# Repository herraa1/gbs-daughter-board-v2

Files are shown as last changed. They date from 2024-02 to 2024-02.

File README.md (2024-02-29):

# GBS Control Daughter Board v2

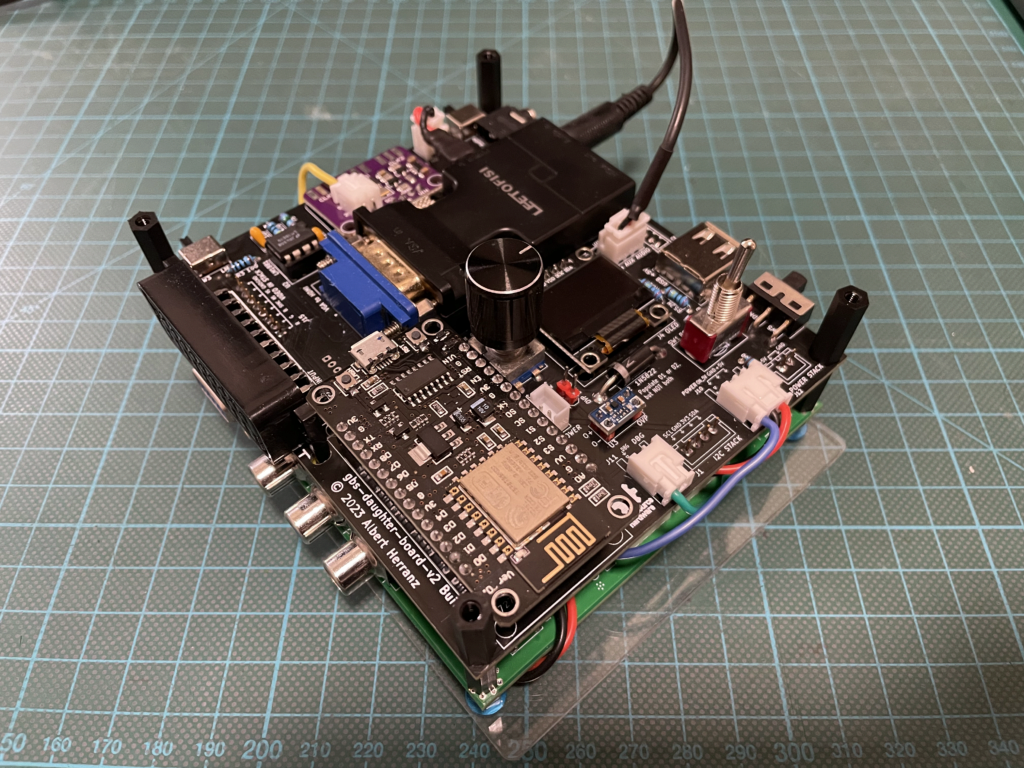
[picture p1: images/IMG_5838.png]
[](images/IMG_5838.png)

Enhance your [GBS8200](https://ramapcsx2.github.io/gbs-control/Wiki/Build-the-Hardware.html) upscaler board.

> [!WARNING]
> This is a work in progress project.
>
> An adapter based on PCB v2 Build1 has been successfully built
>
> No build instructions are yet provided
>

## Introduction

The GBS Daughter Board v2 is a companion board for the GBS8200 upscaler.
It facilitates the upgrade of an off-the-shelf GBS8200 board to a gbs-control firmware based solution, with the following main features:

* HAT-like design, simply stack the daughter board on top of the existing GBS8200
* add SCART RGB input
* add switchable HDMI output (via embedded VGA to HDMI dongle)
* add switchable sync stripper based on the LM1881
* add 3.5" jack sound output
* add switchable common or separate audio ground
* add auxiliar USB socket to optionally power external dongle
* add small OLED screen and rotary encoder for local control

## References

gbs-control
* https://github.com/ramapcsx2/gbs-control

GBS-C AIO
* https://github.com/amoore2600/GBS-C_AIO

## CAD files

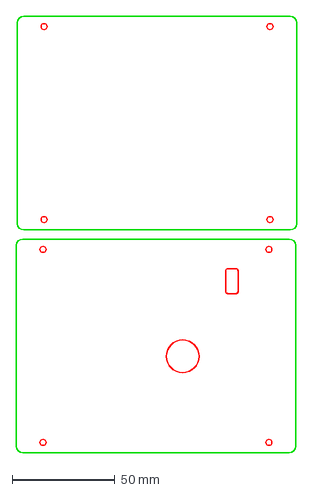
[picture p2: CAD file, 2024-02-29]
enclosure/gbs-daughter-board-v2-case-ready-to-lasercut.dxf
136.5 x 212.5 mm

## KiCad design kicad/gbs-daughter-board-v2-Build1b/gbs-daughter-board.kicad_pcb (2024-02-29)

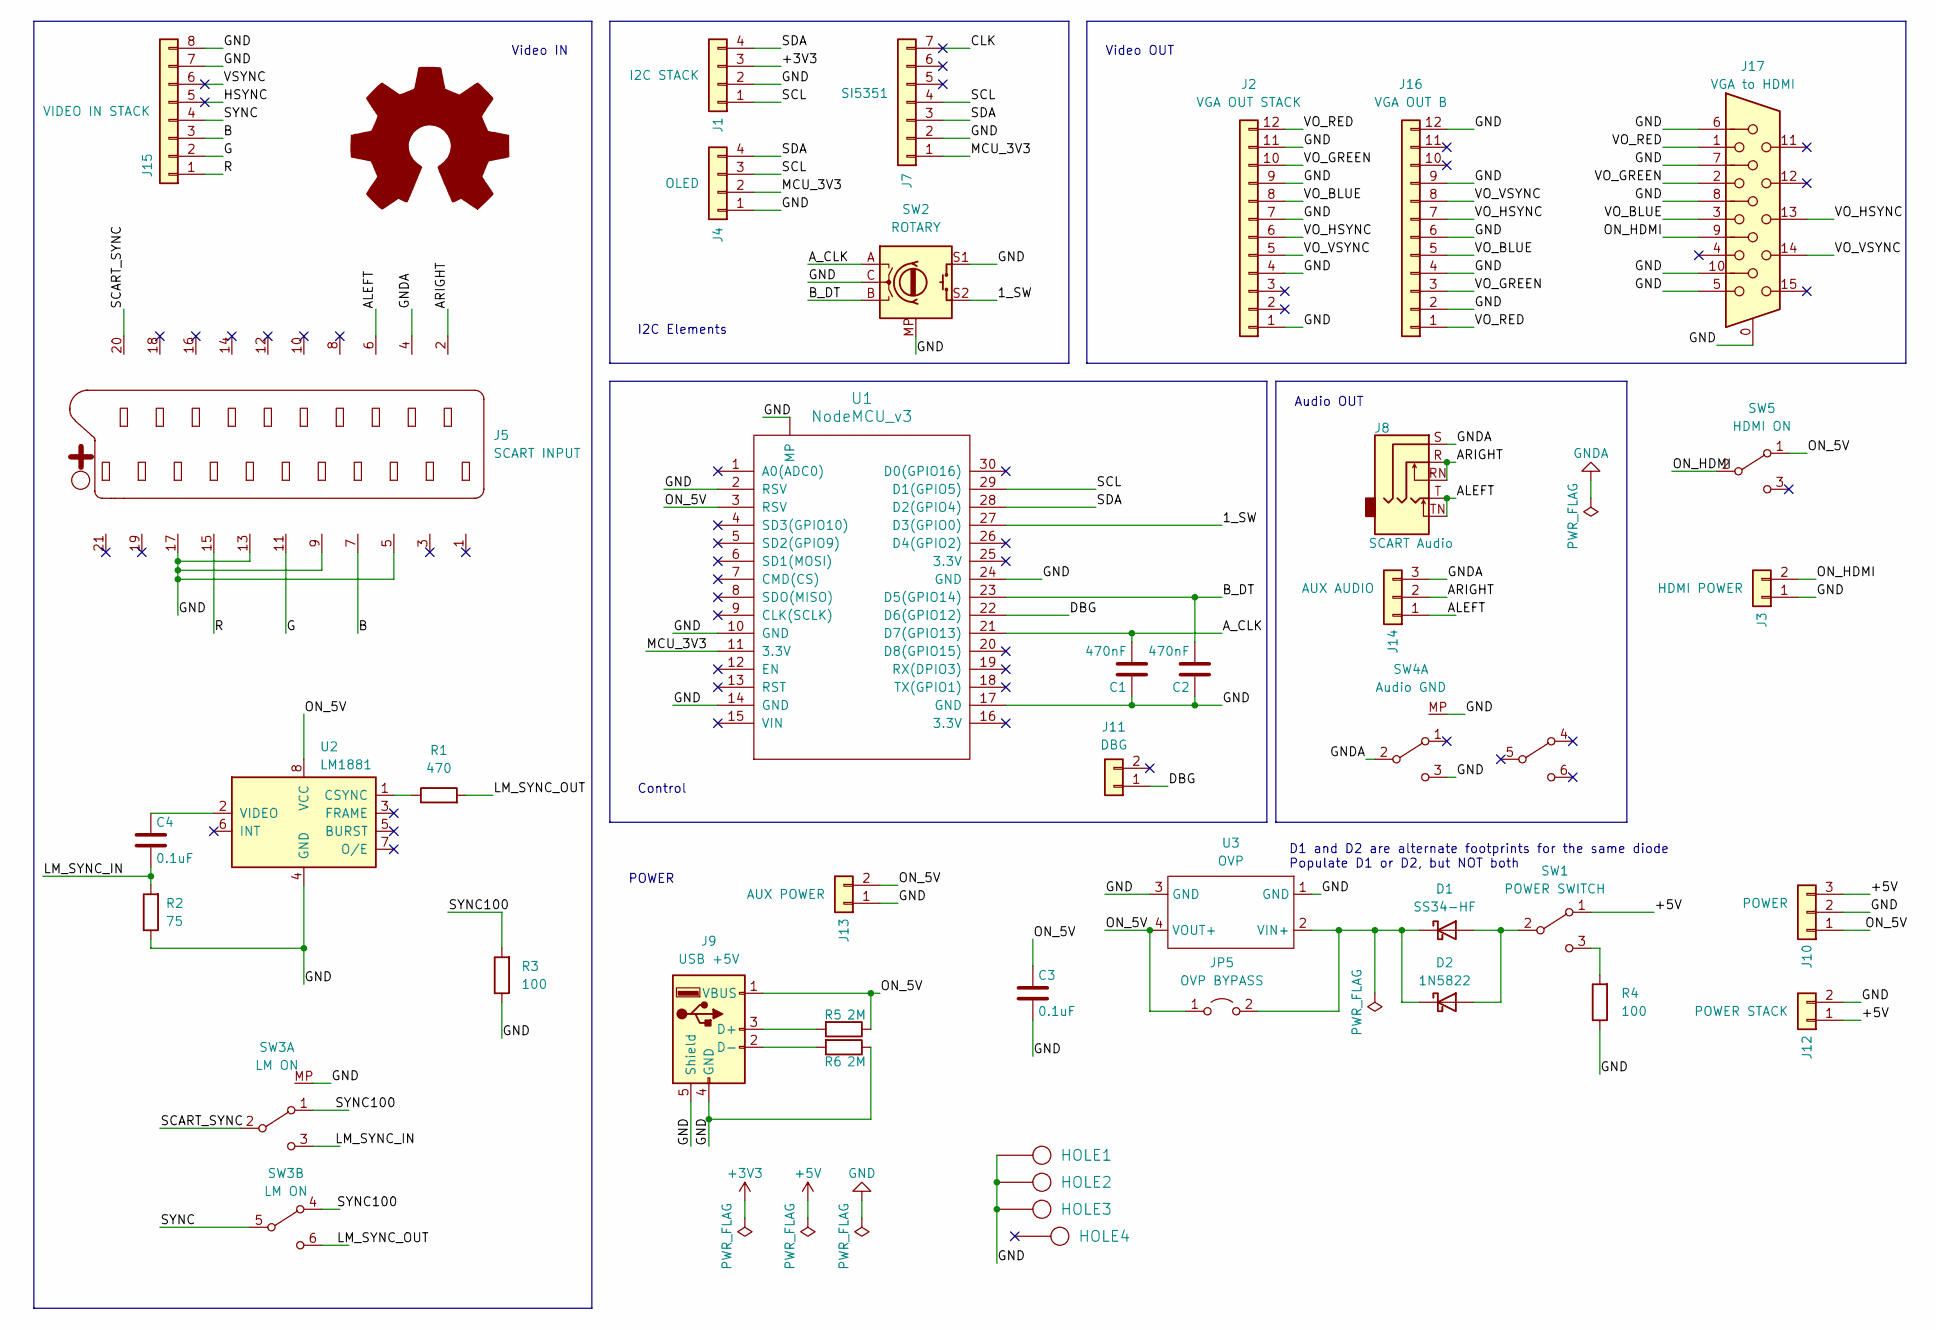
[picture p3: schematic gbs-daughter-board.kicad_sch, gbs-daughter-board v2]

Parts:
C1, C2: 470nF; Cap_Cer_508
C3, C4: 0.1uF; Cap_Cer_508
D1: SS34-HF; D_SMA_Handsoldering
D2: 1N5822; DIODE-DO-27-DO-201AD
HOLE1, HOLE2, HOLE3, HOLE4: HOLE; Hole_3mm
J1: I2C STACK; JST_XH_B4B-XH-A_1x04_P2.50mm_Vertical
J2: VGA OUT STACK; JST_PH_B12B-PH-K_1x12_P2.00mm_Vertical
J3: HDMI POWER; JST_XH_B2B-XH-A_1x02_P2.50mm_Vertical
J4: OLED; Display_128x64_096_I2C
J5: SCART INPUT; SCART
J7: SI5351; si5351a_Module
J8: SCART Audio; Jack_3.5mm_CUI_SJ1-3525N_Horizontal
J9: USB +5V; USB_A_CONNFLY_DS1095-WNR0
J10: POWER; JST_XH_S3B-XH-A_1x03_P2.50mm_Horizontal
J11: DBG; JST_XH_S2B-XH-A_1x02_P2.50mm_Horizontal
J12: POWER STACK; JST_XH_B2B-XH-A_1x02_P2.50mm_Vertical
J13: AUX POWER; JST_XH_B2B-XH-A_1x02_P2.50mm_Vertical
J14: AUX AUDIO; JST_XH_B3B-XH-A_1x03_P2.50mm_Vertical
J15: VIDEO IN STACK; Conn_1x08_P2.50mm
J16: VGA OUT B; JST_PH_S12B-PH-K_1x12_P2.00mm_Horizontal
J17: VGA to HDMI; DSUB-15-HD_Female_Horizontal_P2.29x1.98mm_EdgePinOffset3.03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
JP5: OVP BYPASS; Conn_Pin_Header_2x1_2.54mm_NoKey
R1: 470; Res_762
R2: 75; Res_762
R3, R4: 100; Res_762
R5, R6: 2M; Res_762
SW1: POWER SWITCH; SW_Toggle_Blue_wSlots
SW2: ROTARY; RotaryEncoder_Alps_EC11E-Switch_Vertical_H20mm_CircularMoun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
SW3: LM ON; SW_SK-22D07VG4-2P2T-4mm
SW4: Audio GND; SW_SK-22D07VG4-2P2T-4mm
SW5: HDMI ON; SW_SS-12D11
SYM1: Logo_Open_Hardware_Large; OSHW-Logo_7.5x8mm_SilkScreen
U1: NodeMCU_v3; NodeMCU-LoLinV3-LargePads
U2: LM1881; DIP-8_W7.62mm_Socket
U3: OVP; OVP_Module_5.5V_2.5A_30V

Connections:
+3V3: J1.3
+5V: J10.3, J12.1, SW1.1 (A)
/1_SW: SW2.S2, U1.27 (D3(GPIO0))
/ALEFT: J5.6, J8.T, J8.TN, J14.1
/ARIGHT: J5.2, J8.R, J8.RN, J14.2
/A_CLK: C1.2, SW2.A, U1.21 (D7(GPIO13))
/B: J5.7, J15.3
/B_DT: C2.2, SW2.B, U1.23 (D5(GPIO14))
/CLK: J7.7
/DBG: J11.1, U1.22 (D6(GPIO12))
/G: J5.11, J15.2
/HSYNC: J15.5
/LM_SYNC_IN: C4.2, R2.2, SW3.3 (C)
/LM_SYNC_OUT: R1.2, SW3.6 (C)
/MCU_3V3: J4.2, J7.1, U1.11 (3.3V)
/ON_5V: C3.1, J9.1 (VBUS), J10.1, J13.2, JP5.1 (A), R5.1, SW5.1 (A), U1.3 (RSV), U2.8 (VCC), U3.4 (VOUT+)
/ON_HDMI: J3.2, J17.9, SW5.2 (B)
/R: J5.15, J15.1
/SCART_SYNC: J5.20, SW3.2 (B)
/SCL: J1.1, J4.3, J7.4, U1.29 (D1(GPIO5))
/SDA: J1.4, J4.4, J7.3, U1.28 (D2(GPIO4))
/SYNC: J15.4, SW3.5 (B)
/SYNC100: R3.2, SW3.1 (A), SW3.4 (A)
/VO_BLUE: J2.8, J16.5, J17.3
/VO_GREEN: J2.10, J16.3, J17.2
/VO_HSYNC: J2.6, J16.7, J17.13
/VO_RED: J2.12, J16.1, J17.1
/VO_VSYNC: J2.5, J16.8, J17.14
/VSYNC: J15.6
GND: C1.1, C2.1, C3.2, HOLE1.1, HOLE2.1, HOLE3.1, J1.2, J2.1, J2.4, J2.7, J2.9, J2.11, J3.1, J4.1, J5.5, J5.9, J5.13, J5.17, J7.2, J9.4 (GND), J9.5 (Shield), J10.2, J12.2, J13.1, J15.7, J15.8, J16.2, J16.4, J16.6, J16.9, J16.12, J17.0, J17.5, J17.6, J17.7, J17.8, J17.10, R2.1, R3.1, R4.1, R6.1, SW2.C, SW2.MP, SW2.S1, SW3.MP, SW4.3 (C), SW4.MP, U1. (MP), U1.2 (RSV), U1.10 (GND), U1.14 (GND), U1.17 (GND), U1.24 (GND), U2.4 (GND), U3.1 (GND), U3.3 (GND)
GNDA: J5.4, J8.S, J14.3, SW4.2 (B)
unnamed: D1.2 (A), D2.2 (A), SW1.2 (B)
unnamed: D1.1 (K), D2.1 (K), JP5.2 (B), U3.2 (VIN+)
unnamed: J9.3 (D+), R5.2
unnamed: J9.2 (D-), R6.2
unnamed: R4.2, SW1.3 (C)
unnamed: R1.1, U2.1 (CSYNC)
unnamed: C4.1, U2.2 (VIDEO)

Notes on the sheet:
POWER
Control
I2C Elements
Video IN
Audio OUT
Video OUT
D1 and D2 are alternate footprints for the same diode Populate D1 or D2, but NOT both

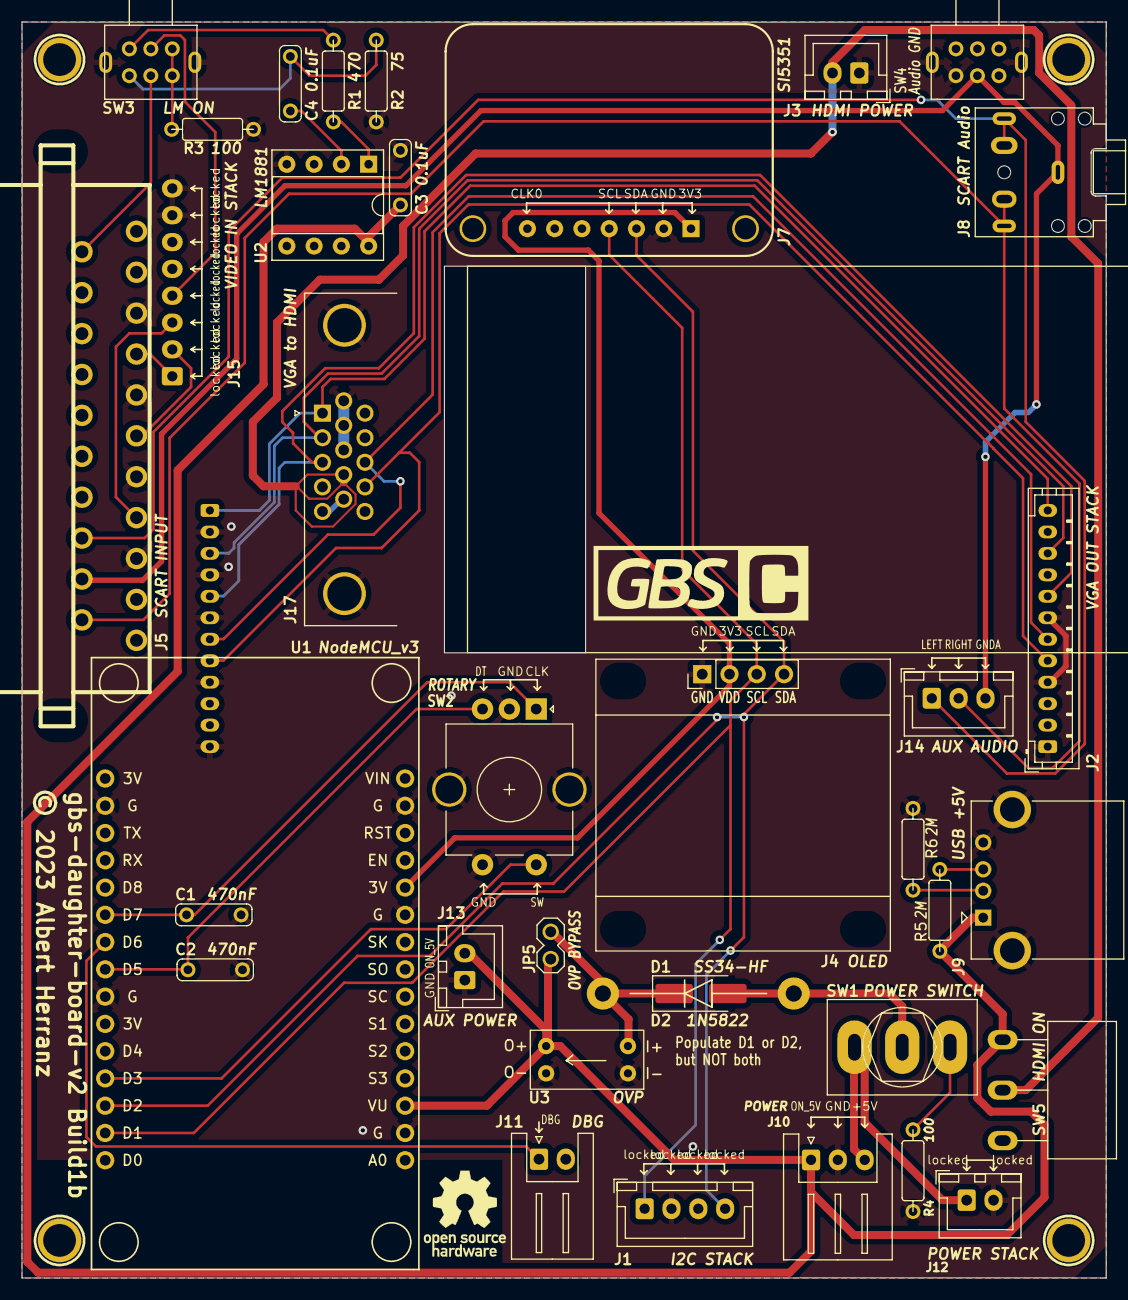
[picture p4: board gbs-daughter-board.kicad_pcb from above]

Board: 2 copper layers, 101.0 x 117.0 mm, 42 parts (1 on the bottom side), 34 nets.

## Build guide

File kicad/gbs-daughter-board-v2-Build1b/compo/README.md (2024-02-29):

kicad-ESP8266 - a library for KiCAD
=====================================
This project has both schematic symbols, footprints, and 3d models for
ESP8266 based modules. It is a work-in-progress. Additions and
corrections are welcome. Enter a pull request or file an issue on
GitHub.

The present modules are:

  * ESP-01  - Note that there are two versions of this module available on
              open market. The schematic symbol is for the `v090` version
              which is probably the same as the `v080`. There is an older
              version that does not include any GPIO signals. The footprint
              is the same for all of the ESP-01 modules.

  * ESP-12  - This is includes an alias part, ESP-07v2, that is suitable
              for the 16 pin variant of the ESP-07. Note that there is a 14
              pin version of the ESP-07 that has different signals and
              pinout. The footprint for the ESP-12 (and ESP-07v2)
              elongated through-hole pads to match those modules.

  * ESP-201 - This is a 26 pin module with pins on 0.1 inch spacing. I
              could not find any official measurements for the pin
              locations so the footprint was created from empirical
              measurements on the unit I have.

  * ESP-12E - This is for the 22 pin variant of the ESP-12. ~~Though all the 
              esp-12 signals are in the same place on ESP-12E, pin numbers
              have changed.~~ As of 2016/12/06 the pin numbers on the
              ESP-12E have been changed to be compatible with the
              ESP-12. If you need the old pin numbers they are still
              available on the `oldNumbers` branch.

  * ESP-07v2 - ESP-07 that is pin compatible with the ESP-12.

  * ESP-13-WROOM-02

  * There is a footprint for the ESP-06, but no supporting
      schematic symbol.

There are 3d models for the ESP-07v2, ESP-13, ESP-12 and ESP-12E.

WARNINGS
---------
  1. The symbols, footprints, and 3d models have not been tested. They are
     based on published images and measurements on individual samples.

  2. The `.dcm` file contains HTML links to information on sites I used
     when creating this library, however I do not have any control over
     the sites themselves. Follow the links with caution.

  3. This library distributed in the hope that it will be useful,
     but __WITHOUT ANY WARRANTY; without even the implied warranty of__
     __MERCHANTABILITY or FITNESS FOR A PARTICULAR PURPOSE__.

Use
---
 1. Clone this archive to a convenient location on your computer. These are
    the commands I use on Linux to create a copy in
    `~/kicad/libraries/kicad-ESP8266`:

        mkdir -p ~/kicad/libraries/
        cd ~/kicad/libraries/
        git clone https://github.com/jdunmire/kicad-ESP8266

 2. Add `ESP8266.lib` to the Component Libraries:

        eeschema:Preferences->Component Libraries->Add

 3. Add `ESP8266.pretty` to the Footprint Libraries:

        pcbnew:Preferences->Footprint Libraries Wizard

 4. To make the 3d models usable, add the location from step #1 to list
    of configured paths as `ESPLIB`. Use a full path. Continuing with
    the example step #1:

        kicad:Preferences->Configure Paths->Add

            Name: ESPLIB
            Path: /home/<your_login_name>/kicad/libraries/kicad-ESP8266

3D Models
---------
The 3D models were built using [OpenSCAD](http://www.openscad.org/) and
then colored in [Wings3D](http://www.wings3d.com/) to produce the VRML
(`.wrl`) format for KiCAD. Wings3D requires a binary STEP format, but
OpenSCAD writes an ASCII version.
[meshconv](http://www.patrickmin.com/meshconv/) will convert the
ASCII format to a binary format.

Here is the workflow I used:

 1. Use OpenScad to build the model. Export the model as STL.
    * Build using F6
    * File->Export...->Export as STL...

 2. Use `meshconv` to translate the file to binary.

        $ meshconv -c stl <STL-FILE-FROM-OpenSCAD> -o <FILENAME>

 3. Now open Wings3d and import the the `FILENAME.stl` as a
 _StereoLithography Binary File (*.stl)_.

 4. Assign colors.

 5. Export as _VRML 2.0 File (*.wrl)_

 6. The 3D model probably needs to be scaled to match the footprint. Use
    the `kicad:Footprint Editor:Edit->Edit Properties->3D Settings`
    dialog. For the ESP-12, the `Shape Scale` X, Y, and Z values are
    0.393700.

This repository includes all the intermediate files:

  * `.scad` - OpenSCAD model
  * `.stl` - OpenSCAD STL
  * `_4wings.stl` - STL file converted by `meshconv`
  * `.wings` - Wings3D model
  * `.wrl` - VRML model for KiCAD

License
-------
Copyright 2015,2016 J.Dunmire

Contact: jedunmire PLUS kicad-ESP8266 AT gmail DOT com

This file is part of kicad-ESP8266. 

kicad-ESP8266 is licensed under the Creative Commons Attribution-ShareAlike
4.0 International License. To view a copy of this license visit
http://creativecommons.org/licenses/by-sa/4.0/.

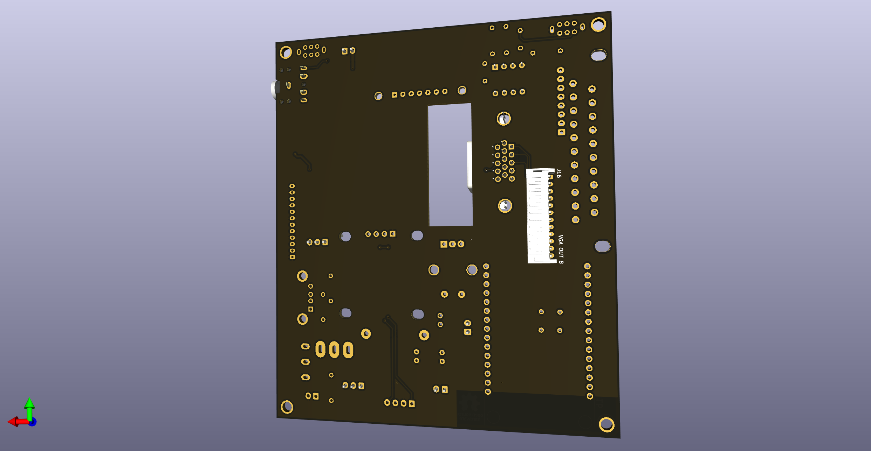
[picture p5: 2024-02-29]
images/gbs-daughter-board-v2-build1b-back.png

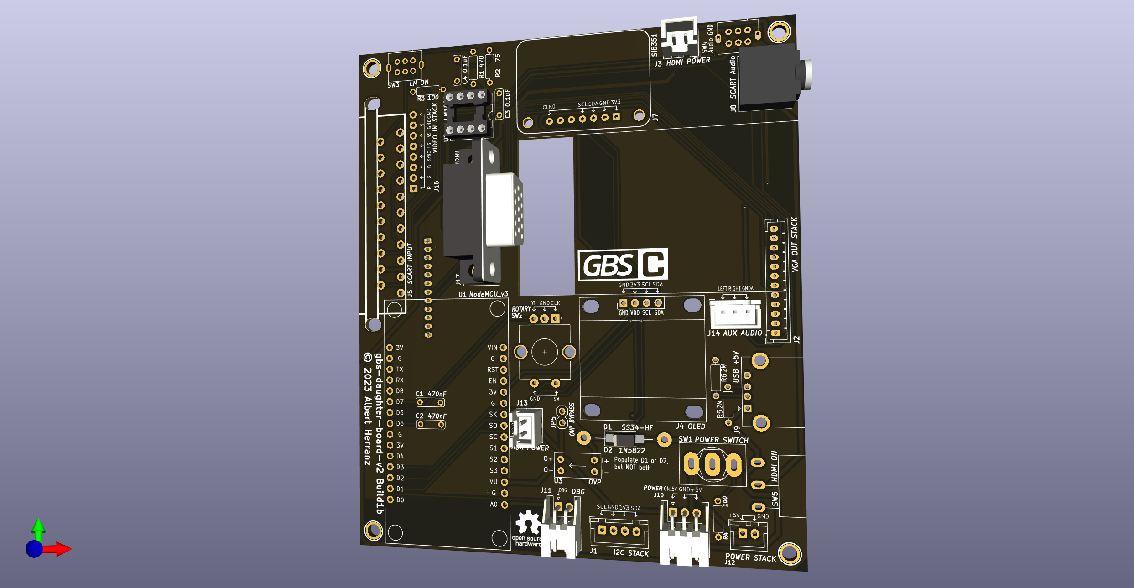
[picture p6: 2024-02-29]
images/gbs-daughter-board-v2-build1b-front.png

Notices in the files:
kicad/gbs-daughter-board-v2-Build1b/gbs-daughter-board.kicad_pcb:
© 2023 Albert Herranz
